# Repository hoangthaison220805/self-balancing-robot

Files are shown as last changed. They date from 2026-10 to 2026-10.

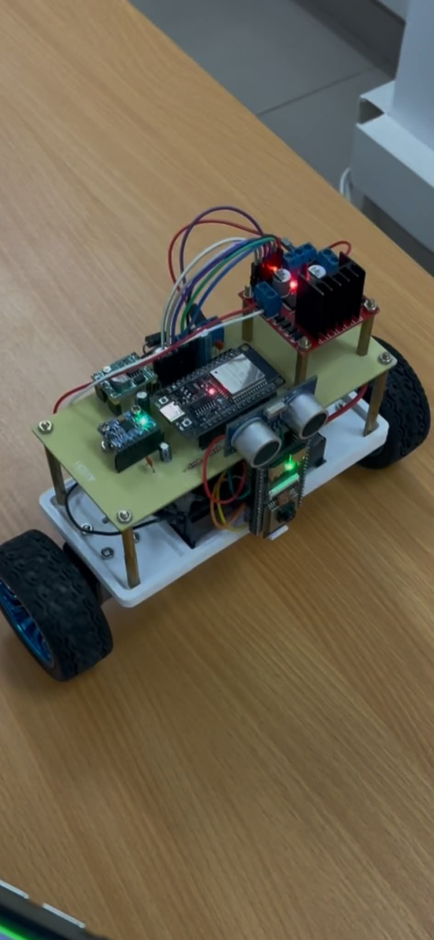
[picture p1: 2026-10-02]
Images/1a0de3ea-6d05-4251-9411-d411f0484698.jpg

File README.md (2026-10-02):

Two-Wheel Self-Balancing Robot with AI Object Detection
Overview

This project presents a two-wheel self-balancing robot based on ESP32-S3 and MPU6050. The robot maintains balance using a PID control algorithm while integrating real-time object detection through an ESP32-CAM and YOLOv11 model.

The system combines embedded control, computer vision, and wireless communication to create an intelligent mobile robotic platform.

Features
Real-time self-balancing using PID control
MPU6050-based angle estimation
Dual DC motor control with encoder feedback
ESP32-S3 firmware running under FreeRTOS
ESP32-CAM video streaming
YOLOv11 object detection and tracking
HTTP communication between vision and control modules
Remote monitoring through a web interface
System Architecture

ESP32-CAM
│
▼
YOLOv11 Detection (PC)
│
HTTP
│
▼
ESP32-S3 Controller
│
▼
PID Balance Control
│
▼
Motor Driver
│
▼
Two-Wheel Robot

Hardware
ESP32-S3
ESP32-CAM
MPU6050 IMU
Dual DC Motors
Motor Driver
Lithium Battery Pack
Custom PCB (Altium Designer)
Software
Arduino IDE
FreeRTOS
Python
OpenCV
Ultralytics YOLOv11
Repository Structure

firmware/
├── esp32s3_balance/

vision/
├── detect.py
├── best.pt
└── requirements.txt

hardware/
├── schematic/
├── pcb/

docs/
└── report/

Results

The robot is capable of maintaining stable balance in real time while performing object detection through the ESP32-CAM. The system demonstrates the integration of embedded control algorithms and AI-based computer vision on a low-cost robotic platform.

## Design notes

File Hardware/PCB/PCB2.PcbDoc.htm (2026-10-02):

Altium Reporting Options

# File in Newer Format

Date | : | 18/06/2026
Time | : | 12:58:06 SA
Filename | : | C:\Users\Admin\AppData\Local\Temp\Zalo Temp\37d5b8bf03f8b2f1d817bfa98e7e1c87~\PCB\PCB2.PcbDoc

Version | Warning
Release 10 | CAUTION - New Custom Grids and Guides were introduced. Be aware that your design might contain Custom Grids and Guides that cannot be read in previous versions.
Release 10 | CAUTION - New Structured Clusters were introduced. Be aware that your design might contain Structured Clusters that cannot be read in previous versions.
Release 10 | CAUTION - New PCB 3D Movie Manager was introduced. Be aware that your design might contain 3D PCB movie that cannot be read in previous versions.
Release 10 update 1 | CAUTION - New Clearance Rule subscopes targeting differential pairs were introduced. Be aware that your design might contain Clearance Rules using those subscopes that cannot be read in previous versions.
Release 10 update 15 | CAUTION - Support of Solder Mask and Paste Mask expansions for Tracks, Arcs, Fills and Regions was introduced. Be aware that your design might contain Solder Mask and Paste Mask expansions for these types of primitives that cannot be read in the version of Altium Designer you are currently using.
Release 12 | CAUTION - Air Gap Width previously controlled by Clearance rule is now controlled by Polygon Connect Style rule's newly introduced Air Gap Width (set to default value). Suggest reviewing each Polygon Connect Style rule's Air Gap Width attribute for correctness.
Release 13 | CAUTION - Silk To Solder Mask Clearance Rules are converted to Silkscreen Over Component Pads Rules.
Release 14 | CAUTION - The Differential Pairs Routing rule added support for control of the width. Be aware that these widths must be manually entered as Width rules in this version.
Release 15 | CAUTION - Support of separate solder masks for top & bottom of pads added.
Release 15.1 | CAUTION - Support Multi-line PCB Text added.
Release 16.0 | CAUTION - Pad/Via hole size tolerance value added.
Release 17.0 | CAUTION - Component parameters added.
Release 17.0 | CAUTION - Support of backdrilling
Release 17.1 | CAUTION - Support of waived violations
Release 17.1 | CAUTION - Support of object specific keepouts
Release 20.0 | CAUTION - Support of propagation delay for primitives

This file was generated by a later version of the software

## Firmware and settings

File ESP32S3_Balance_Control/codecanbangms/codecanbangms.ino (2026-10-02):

#include "PID_v1.h"
#include "I2Cdev.h"
#include "MPU6050_6Axis_MotionApps20.h"
#include "Wire.h"

// THÔNG SỐ CÂN BẰNG 
double originalSetpoint = 183.66; //177.3
double setpoint = originalSetpoint;
double movingAngleOffset = 2.0; 
double turnSpeedOffset = 40;    
volatile char command = 'S'; 

double input, output;
double Kp = 40.0;  
double Ki = 150.0; 
double Kd = 1.0;  
PID pid(&input, &output, &setpoint, Kp, Ki, Kd, DIRECT);

const int ENA = 25, IN1 = 26, IN2 = 27, IN3 = 14, IN4 = 12, ENB = 13;
double motorSpeedFactor = 0.8; 
#define MIN_ABS_SPEED 45        

// THÔNG SỐ SIÊU ÂM 
#define TRIG_PIN 4   
#define ECHO_PIN 2
volatile int distance = 999; 

// MPU6050 
MPU6050 mpu;
bool dmpReady = false;  
uint8_t devStatus;      
uint16_t packetSize;    
uint8_t fifoBuffer[64]; 
Quaternion q;           
VectorFloat gravity;    
float ypr[3];           

TaskHandle_t TaskDistance;

void DistanceTaskCode(void * pvParameters) {
  pinMode(TRIG_PIN, OUTPUT); pinMode(ECHO_PIN, INPUT);
  for(;;) {
    digitalWrite(TRIG_PIN, LOW); delayMicroseconds(2);
    digitalWrite(TRIG_PIN, HIGH); delayMicroseconds(10);
    digitalWrite(TRIG_PIN, LOW);
    long duration = pulseIn(ECHO_PIN, HIGH, 25000); 
    int tempDist = duration * 0.034 / 2;
    distance = (tempDist > 0 && tempDist < 400) ? tempDist : 999;
    vTaskDelay(100 / portTICK_PERIOD_MS); 
  }
}

//  ĐIỀU KHIỂN ĐỘNG CƠ CÓ DEADBAND
void moveTurn(double speedLeft, double speedRight) {
  // NGUYÊN LÝ 2: Vùng chết (Deadband) - Chống rung khi xe đã cân bằng
  if (abs(speedLeft) < 5) speedLeft = 0;
  if (abs(speedRight) < 5) speedRight = 0;

  // Bánh trái
  if (speedLeft < 0) { digitalWrite(IN1, LOW); digitalWrite(IN2, HIGH); } 
  else if (speedLeft > 0) { digitalWrite(IN1, HIGH); digitalWrite(IN2, LOW); }
  else { digitalWrite(IN1, LOW); digitalWrite(IN2, LOW); } // Phanh
  
  int pwmLeft = 0;
  if (speedLeft != 0) {
      pwmLeft = constrain(abs(speedLeft) * motorSpeedFactor, 0, 255);
      if (pwmLeft < MIN_ABS_SPEED) pwmLeft = MIN_ABS_SPEED;
  }
  ledcWrite(ENA, pwmLeft);

  // Bánh phải
  if (speedRight < 0) { digitalWrite(IN3, LOW); digitalWrite(IN4, HIGH); } 
  else if (speedRight > 0) { digitalWrite(IN3, HIGH); digitalWrite(IN4, LOW); }
  else { digitalWrite(IN3, LOW); digitalWrite(IN4, LOW); } // Phanh
  
  int pwmRight = 0;
  if (speedRight != 0) {
      pwmRight = constrain(abs(speedRight) * motorSpeedFactor, 0, 255);
      if (pwmRight < MIN_ABS_SPEED) pwmRight = MIN_ABS_SPEED;
  }
  ledcWrite(ENB, pwmRight);
}

void setup() {
    Serial.begin(115200); 
    Serial2.begin(115200, SERIAL_8N1, 16, 17);
    
    pinMode(IN1, OUTPUT); pinMode(IN2, OUTPUT); pinMode(IN3, OUTPUT); pinMode(IN4, OUTPUT);
    ledcAttach(ENA, 500, 8); ledcAttach(ENB, 500, 8);
    Wire.begin(21, 22); Wire.setClock(400000);
    
    xTaskCreatePinnedToCore(DistanceTaskCode, "DistTask", 4000, NULL, 1, &TaskDistance, 0);

    mpu.initialize(); 
    devStatus = mpu.dmpInitialize();
    mpu.setXGyroOffset(73); mpu.setYGyroOffset(-50); mpu.setZGyroOffset(41); mpu.setZAccelOffset(805); //-54

    if (devStatus == 0) {
        mpu.setDMPEnabled(true);
        dmpReady = true;
        packetSize = mpu.dmpGetFIFOPacketSize();
        pid.SetMode(AUTOMATIC);
        pid.SetSampleTime(10);
        pid.SetOutputLimits(-255, 255);  
    }
}

void loop() {
    if (!dmpReady) return;

    if (Serial2.available()) {
        char c = Serial2.read();
        if (c == 'F' || c == 'B' || c == 'L' || c == 'R' || c == 'S') {
            command = c;
        }
    }

    if (distance > 0 && distance < 20 && command == 'F') {
        command = 'S'; 
    }

    double targetSetpoint = originalSetpoint;
    double leftTurn = 0, rightTurn = 0;

    // NGUYÊN LÝ 1: Vgo - Cộng offset cố định vào mục tiêu
    switch (command) {
        case 'F': targetSetpoint = originalSetpoint + movingAngleOffset; break;
        case 'B': targetSetpoint = originalSetpoint - movingAngleOffset; break;
        case 'L': leftTurn = turnSpeedOffset; rightTurn = -turnSpeedOffset; break;
        case 'R': leftTurn = -turnSpeedOffset; rightTurn = turnSpeedOffset; break;
        default:  targetSetpoint = originalSetpoint; // Xóa sạch tích lũy Ki khi dừng để không bị trôi
         break;
    }

    // NGUYÊN LÝ LÀM MƯỢT BẰNG LỌC THÔNG THẤP (Low-pass filter)
    
    
    setpoint = (setpoint * 0.95) + (targetSetpoint * 0.05);

    if (mpu.getFIFOCount() >= packetSize) {
        mpu.getFIFOBytes(fifoBuffer, packetSize);
        mpu.dmpGetQuaternion(&q, fifoBuffer);
        mpu.dmpGetGravity(&gravity, &q);
        mpu.dmpGetYawPitchRoll(ypr, &q, &gravity);
        input = ypr[1] * 180/M_PI + 180;
        
        // Ngắt động cơ nếu góc nghiêng quá lớn (Ngã xe)
        if (input < 150 || input > 210) {
            moveTurn(0, 0);
            return;
        }

        pid.Compute();
        
        // NGUYÊN LÝ 3: Trộn tín hiệu Rẽ trực tiếp vào Output
        moveTurn(output + leftTurn, output + rightTurn);
    }
}

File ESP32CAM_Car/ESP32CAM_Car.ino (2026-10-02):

/* ESP32-S3 Camera Car - Optimized for N16R8 */

#include "esp_camera.h"
#include <WiFi.h>

// Định nghĩa chân cho ESP32-S3 (Sơ đồ chân chuẩn Freenove / AI-Thinker S3)
#define PWDN_GPIO_NUM     -1
#define RESET_GPIO_NUM    -1
#define XCLK_GPIO_NUM     15
#define SIOD_GPIO_NUM      4
#define SIOC_GPIO_NUM      5

#define Y9_GPIO_NUM       16
#define Y8_GPIO_NUM       17
#define Y7_GPIO_NUM       18
#define Y6_GPIO_NUM       12
#define Y5_GPIO_NUM       10
#define Y4_GPIO_NUM        8
#define Y3_GPIO_NUM        9
#define Y2_GPIO_NUM       11
#define VSYNC_GPIO_NUM     6
#define HREF_GPIO_NUM      7
#define PCLK_GPIO_NUM     13


const char* ap_ssid = "ESP32-S3-CAR";
const char* ap_password = "12345678";

String WiFiAddr ="";

void startCameraServer();

void setup() {
  Serial.begin(115200);
  Serial.setDebugOutput(true);
  
  
  Serial2.begin(115200, SERIAL_8N1, 39, 38); //39 rx 38 txnoi vs 16



  camera_config_t config;
  config.ledc_channel = LEDC_CHANNEL_0;
  config.ledc_timer = LEDC_TIMER_0;
  config.pin_d0 = Y2_GPIO_NUM;
  config.pin_d1 = Y3_GPIO_NUM;
  config.pin_d2 = Y4_GPIO_NUM;
  config.pin_d3 = Y5_GPIO_NUM;
  config.pin_d4 = Y6_GPIO_NUM;
  config.pin_d5 = Y7_GPIO_NUM;
  config.pin_d6 = Y8_GPIO_NUM;
  config.pin_d7 = Y9_GPIO_NUM;
  config.pin_xclk = XCLK_GPIO_NUM;
  config.pin_pclk = PCLK_GPIO_NUM;
  config.pin_vsync = VSYNC_GPIO_NUM;
  config.pin_href = HREF_GPIO_NUM;
  config.pin_sscb_sda = SIOD_GPIO_NUM;
  config.pin_sscb_scl = SIOC_GPIO_NUM;
  config.pin_pwdn = PWDN_GPIO_NUM;
  config.pin_reset = RESET_GPIO_NUM;
  config.xclk_freq_hz = 20000000;
  config.pixel_format = PIXFORMAT_JPEG;
  
 
  if(psramFound()){
    config.frame_size = FRAMESIZE_UXGA; 
    config.fb_count = 2;
    config.fb_location = CAMERA_FB_IN_PSRAM; 
  } else {
    config.frame_size = FRAMESIZE_SVGA;
    config.jpeg_quality = 12;
    config.fb_count = 1;
  }

  // Khởi tạo Camera
  esp_err_t err = esp_camera_init(&config);
  if (err != ESP_OK) {
    Serial.printf("Camera init failed error 0x%x", err);
    return;
  }

  sensor_t * s = esp_camera_sensor_get();
  s->set_framesize(s, FRAMESIZE_QVGA); // Để stream mượt cho xử lý ảnh

  // Chế độ Access Point
  WiFi.softAP(ap_ssid, ap_password);
  IPAddress IP = WiFi.softAPIP();
  Serial.print("\nAP Started! IP: ");
  Serial.println(IP);
  
  startCameraServer();
}

void loop() {
  // Loop để trống vì Web Server chạy ngầm
  delay(1);
}
